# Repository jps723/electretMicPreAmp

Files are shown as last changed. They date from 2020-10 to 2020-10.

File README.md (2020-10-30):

# Electret Mic Preamp Build Notes 2/24/20

This project is in partnership with [Bantam Tools](https://www.bantamtools.com)

**Design Notes:**

This Electret Mic Preamp is a passive preamplifier and is based around the [LM358 op amp](https://www.ti.com/product/LM358).  This is a dual operational amplifier where in this circuit we are utilizing only one of the amplifiers on pins 1, 2, and 3.  Pin 4 is the Ground, where pin 8 is VCC.  


Pin 8 is powered by a 5v source, through two capacitors for filtering out high/low level noise (C2 and C3).  The electret mic is powered through a 10k resistor (R1), where the signal then goes through a coupling capacitor (C1) before a 1k resistor (R2) and entering pin 2.  A 200k variable resistor (VR1) serves to create feedback and the relationship between R2 and VR1 establishes the potential gain of the signal being represented by Gain = VR1/R2.  In this circuit, there is a potential gain of up to 200x the original signal (200k/1k = 200), allowing for a wide range of adjustment.

Two 100k resistors (R4/R5) are connected to GND and VCC respectively, prior to connecting to pin 3, for setting the potential voltage (2.5v). The circuit also has a power indicating LED for showing that the unit is powered on.

# Build Process
**Bits:**
1/32”
1/64”
**Mill Time:**
6m15s

It’s easiest to solder in this order:
```
1. Resistors
2. Ceramic Caps
3. Electret Mic
4. Dip Socket
5. LED
6. Electrolytic Caps
7. Screw Terminal
8. Potentiometer
```

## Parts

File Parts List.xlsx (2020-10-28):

Part | Quantity | Notes
Resistors
100k | 2
10k | 2
1k | 1
Ceramic Capacitors
.1uF | 2
Electrolytic Capacitors
470uF | 1
10uF | 1
Screw Terminal | 1 | 1x2
Dip Socket | 1 | 2x4
Potentiometer | 1 | 200k Footprint: https://www.mouser.com/ProductDetail/858-P0915NEC20BR100K
Horizontal Audio Jack | 1 | Footprint: https://www.amazon.com/gp/product/B008SNZUYC/ref=ppx_yo_dt_b_asin_title_o04_s00?ie=UTF8&psc=1
LED | 1
Electret Mic | 1

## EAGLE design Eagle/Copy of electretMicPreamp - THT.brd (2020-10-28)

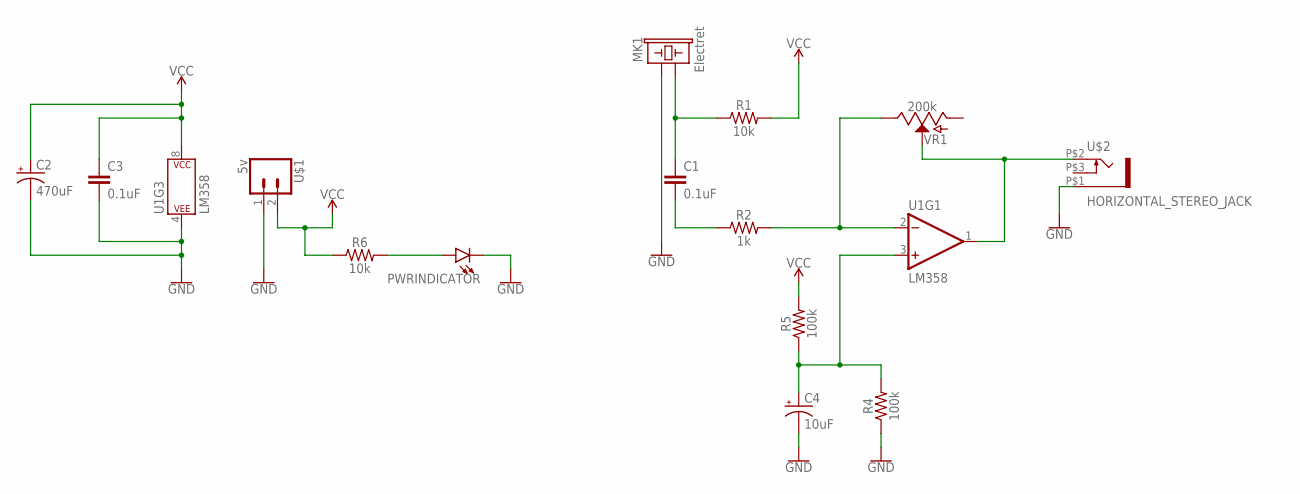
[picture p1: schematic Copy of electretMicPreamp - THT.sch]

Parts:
C1, C3: 0.1uF; CAP-PTH-SMALL-KIT
C2: 470uF; CPOL-RADIAL-2.5MM-5MM
C4: 10uF; CPOL-RADIAL-2.5MM-5MM
MK1: Electret; MICROPHONE-PTH-9.7MM
PWRINDICATOR: LED-3MM-NO_SILK; LED_3MM-NS
R1, R6: 10k; AXIAL-0.3
R2: 1k; AXIAL-0.3
R4, R5: 100k; AXIAL-0.3
U1: LM358; DIP08-KIT
U$1: 5v; SCREWTERMINAL-2X1
U$2: HORIZONTAL_STEREO_JACK
VR1: 200k; POT-PTH-ALPS

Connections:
GND: C2.2 (-), C3.2, C4.2 (-), MK1.1, PWRINDICATOR.K (C), R4.P$1 (1), U1.4 (P$V-), U$1.1, U$2.P$1 (1)
unnamed: C1.1, MK1.2, R1.P$1 (1)
unnamed: C1.2, R2.P$1 (1)
unnamed: R2.P$2 (2), U1.2 (-IN), VR1.P$1 (E)
unnamed: U1.1 (OUT), U$2.P$2 (2), VR1.P$2 (S)
unnamed: PWRINDICATOR.A, R6.P$2 (2)
unnamed: C4.1 (+), R4.P$2 (2), R5.P$1 (1), U1.3 (+IN)
VCC: C2.1 (+), C3.1, R1.P$2 (2), R5.P$2 (2), R6.P$1 (1), U1.8 (P$V+), U$1.2

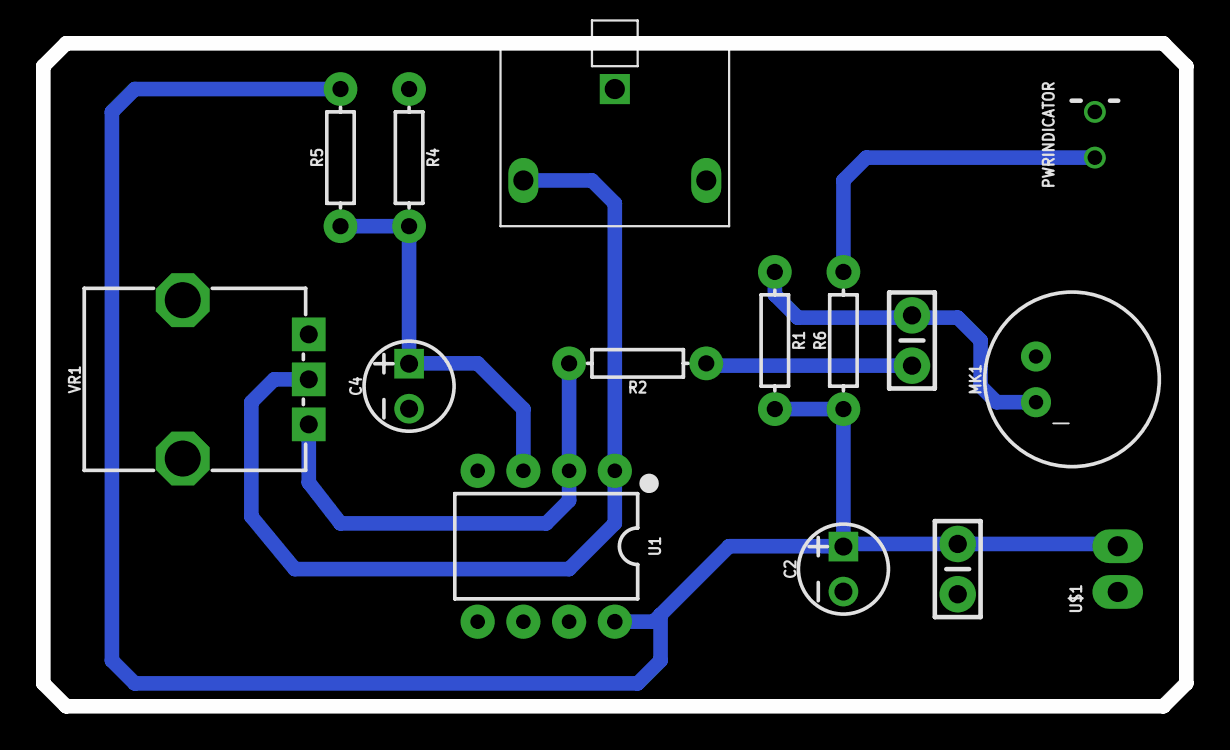
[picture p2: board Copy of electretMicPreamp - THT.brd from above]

Board: 2 copper layers, 63.5 x 36.8 mm, 15 parts (0 on the bottom side), 8 nets.

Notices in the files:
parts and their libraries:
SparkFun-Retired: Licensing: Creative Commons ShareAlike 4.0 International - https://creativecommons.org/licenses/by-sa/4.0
